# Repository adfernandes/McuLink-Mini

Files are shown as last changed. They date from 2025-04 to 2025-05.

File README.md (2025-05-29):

# MCU-Link with KiCAD
This repository hosts different versions of the original NXP MCU-Link CMSIS-DAP debug probe as open source KiCAD versions. Both as standalone probe or integrated into your design.

Many thanks to *Dario Scheuber* and his work to make this project possible!

## Background
This is the work of Dario Scheuber who created this debug probe as student at the Lucerne University of Applied Sciences and Arts at [IET](https://www.hslu.ch/en/lucerne-school-of-engineering-architecture/about-us/organization/institute/engineering-and-technology/elektrotechnik/). The project was done under the guidance of Prof. Erich Styger.

See blog article on https://mcuoneclipse.com/2024/02/06/versatile-oshw-mini-mcu-link-debug-probe-external-on-board-or-embedded/ for additional details.

## Features
This is an open hardware version of the NXP MCU-Link CMSIS-DAP debug probe, with following features and differences to the original MCU-Link:
- Open hardware design with KiCad
- Firmware compatibility with MCU-Link (LinkServer, CMSIS-DAP, ARM DAPLink)
- Dual-Layer design for lower costs
- USB-C connector instead of  Micro-USB
- USB-C connector usable to debug the LPC55S69
- 30% smaller than the original MCU-Link
- Firmware/boot push button instead of jumper
- Micro connector for UART connection instead of pin header
- Supports only 3.3V targets (no level shifters)
- Standalone version as external debug probe
- On-Board version: Solder external debug probe on your custom board (castellated pins)
- Embedded version: copy-paste into your custom board KiCad design
- BOM with assembly costs: ~$12/piece for 100 units

top PCB
bottom PCB

## Folders
- enclosure: 3D printed enclosure
- hardware: KiCad and hardware related files

## Links
- Article: https://mcuoneclipse.com/2024/02/06/versatile-oshw-mini-mcu-link-debug-probe-external-on-board-or-embedded/
- NXP MCU-Link: https://www.nxp.com/design/design-center/software/development-software/mcuxpresso-software-and-tools-/mcu-link-debug-probe:MCU-LINK
- KiCad: https://www.kicad.org/

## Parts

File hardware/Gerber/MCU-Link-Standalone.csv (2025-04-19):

ID | Label | Footprint | Number | Description, Value | Reference
1 | JP1 | SolderJumper-2_P1.3mm_Open_RoundedPad1.0x1.5mm | 1 | SWD disable
2 | C22,C15,C26 | C_0402_1005Metric | 3 | 22u
3 | C21,C24 | C_0402_1005Metric | 2 | 8p
4 | J2 | JST_BM03B-SRSS-TB_LF__SN_ | 1 | BM03B-SRSS-TB
5 | U2 | LQFP-64-1EP_10x10mm_P0.5mm_EP5x5mm | 1 | LPC55S69JBD64
6 | L5 | L_0603_1608Metric | 1 | 4u7
7 | C8,C7,C25,C9,C5,C2,C18,C4,C11,C17 | C_0402_1005Metric | 10 | 100n
8 | D5,D2 | SOT-666 | 2 | PESD5V0L5UV
9 | Q2,Q3,Q1 | SOT1216 | 3 | PMDXB290UNE
10 | C10,C1 | C_0402_1005Metric | 2 | 10u
11 | R12,R6,R8,R5,R7,R9 | R_0402_1005Metric | 6 | 100
12 | C23,C19,C20 | C_0402_1005Metric | 3 | 47p
13 | SW1 | SW_C_K_KMR2 | 1 | KMR221GLFS
14 | D1 | SOT143B | 1 | PRTR5V0U2X
15 | R1,R2 | R_0402_1005Metric | 2 | 5k1
16 | U1 | SOT-89-5 | 1 | XC6227C331PR-G
17 | D3 | LED_0402_1005Metric | 1 | LED_RED
18 | C13,C6,C14,C12,C16 | C_0402_1005Metric | 5 | 10n
19 | L3,L4,L2 | L_0603_1608Metric | 3 | MI0603J601R-10
20 | R13,R14 | R_0402_1005Metric | 2 | 100k
21 | R11,R15 | R_0402_1005Metric | 2 | 2k
22 | R4 | R_0402_1005Metric | 1 | 20k
23 | U3 | SOT95P280X145-5N | 1 | STMPS2141STR
24 | D4 | Nexperia_DSN0603-2_0.6x0.3mm_P0.4mm | 1 | PMEG3005AESFYL
25 | J1 | USB_C_Receptacle_GCT_USB4110-GF-A | 1 | USB4110-GF-A_REVB
26 | R10,R3 | R_0402_1005Metric | 2 | 10k
27 | Y1 | CX3225GA16000D0PTVCC | 1 | 16.000MHz
28 | C3 | C_0402_1005Metric | 1 | 4u7
29 | R16 | R_0402_1005Metric | 1 | 10
30 | J3 | SWD_Pin_Header_Straight_2x05_Pitch1.27mm_SMD | 1 | Conn_02x05_Odd_Even

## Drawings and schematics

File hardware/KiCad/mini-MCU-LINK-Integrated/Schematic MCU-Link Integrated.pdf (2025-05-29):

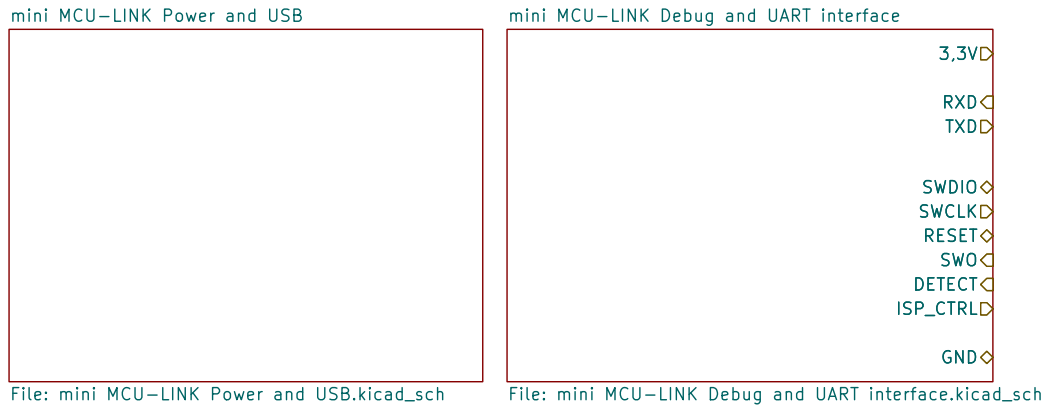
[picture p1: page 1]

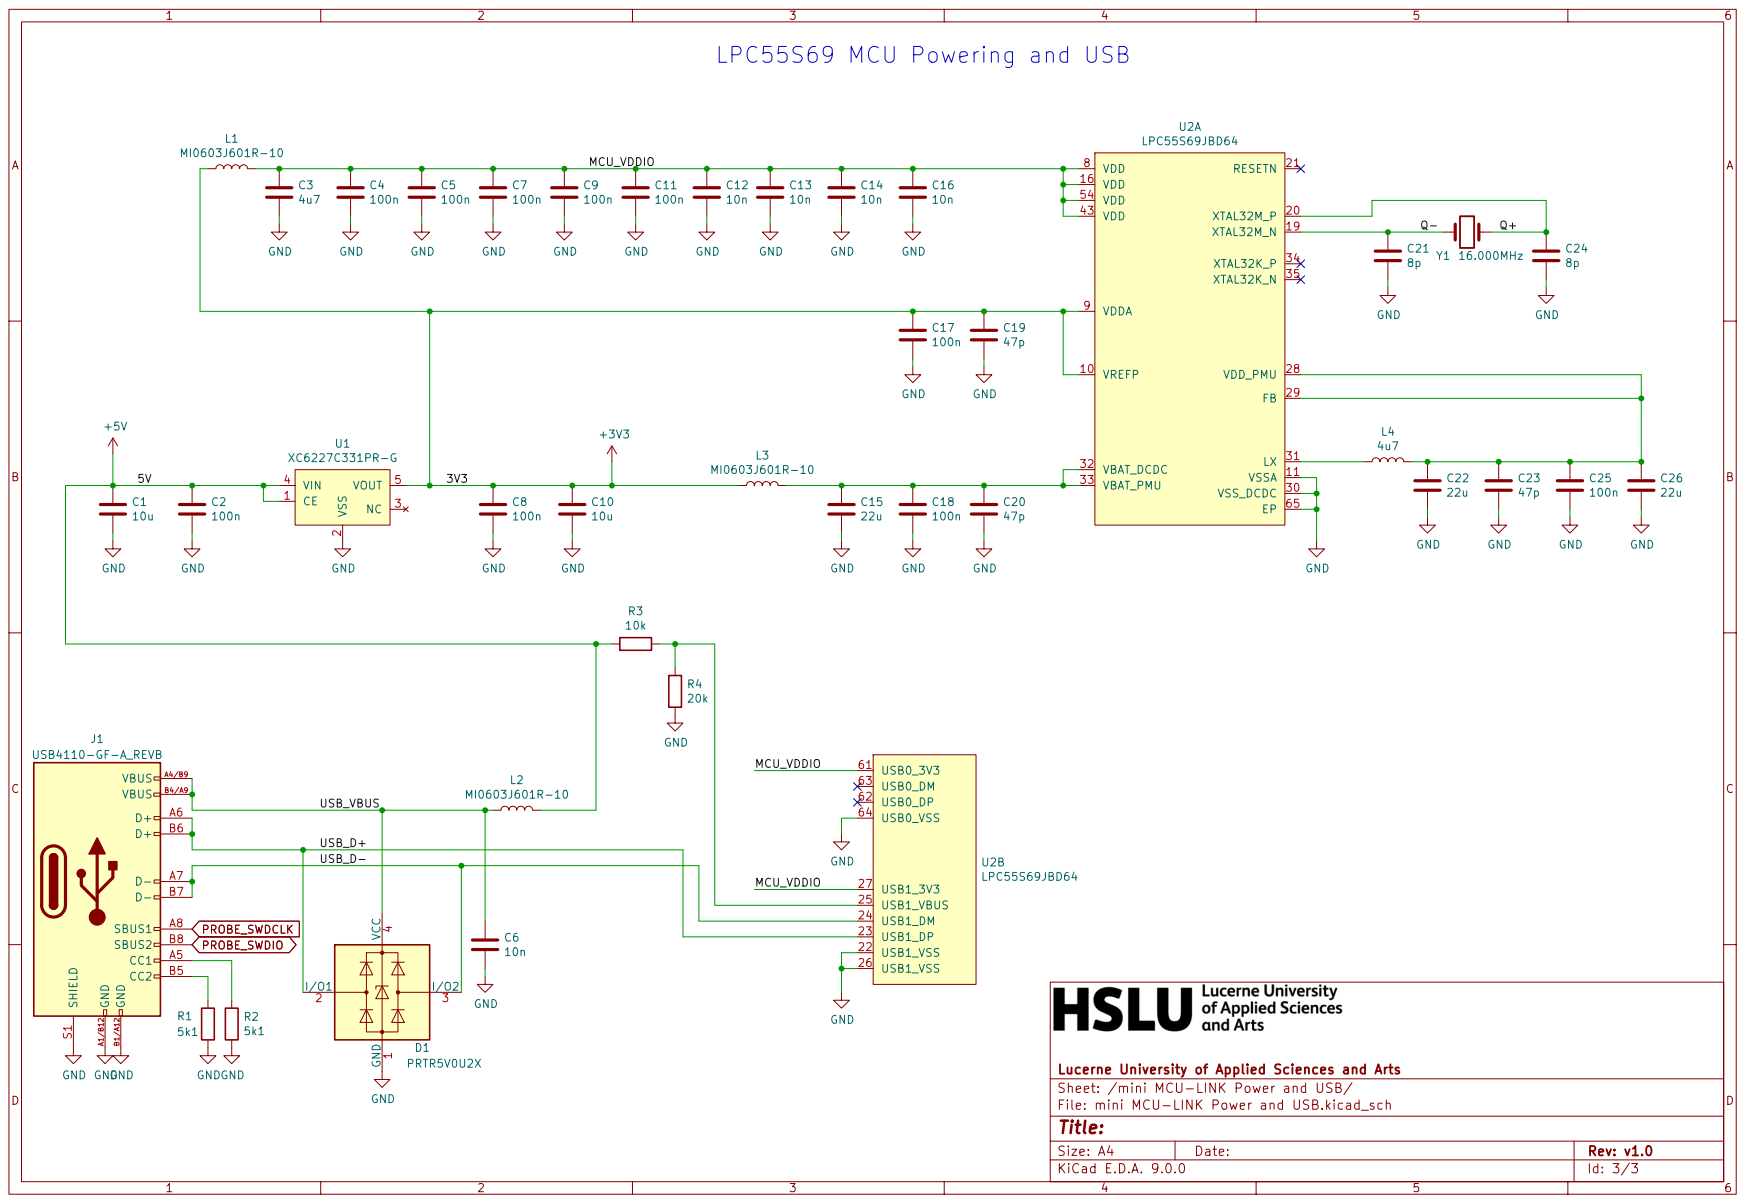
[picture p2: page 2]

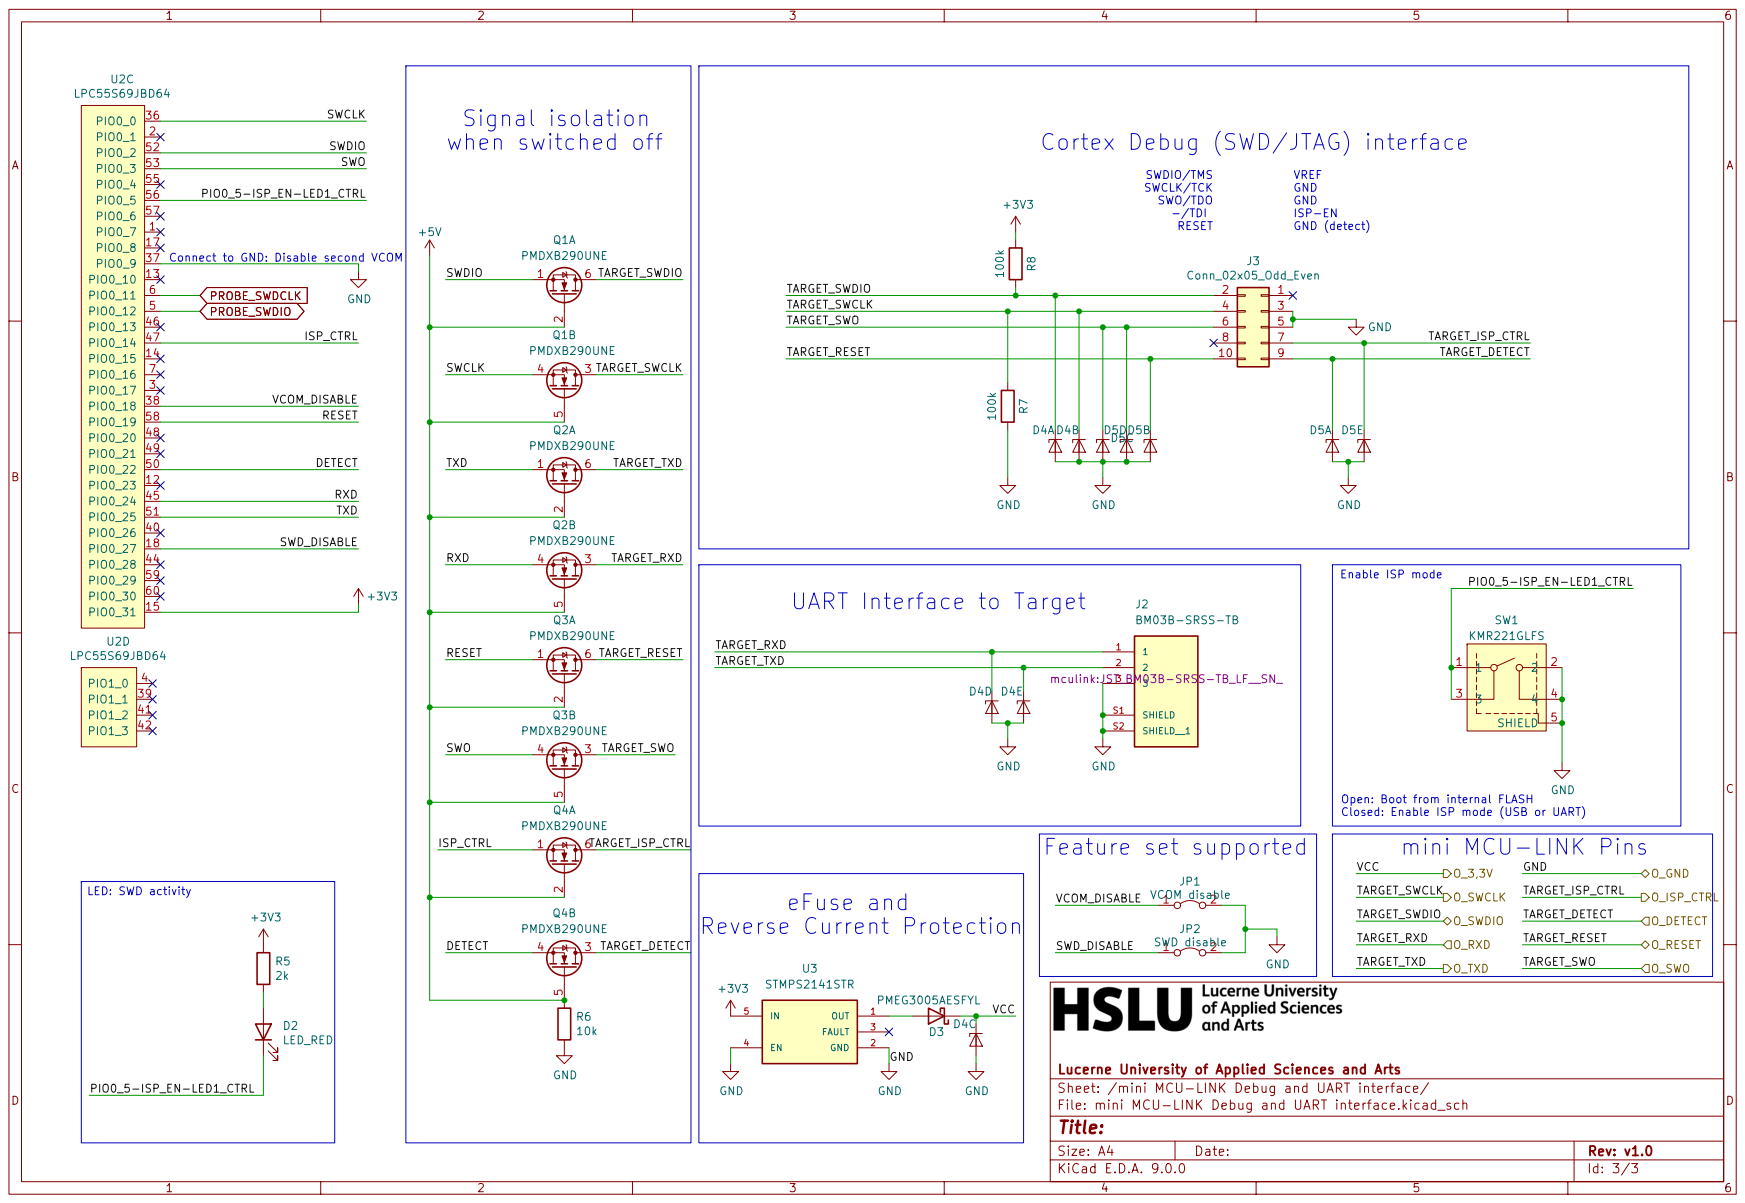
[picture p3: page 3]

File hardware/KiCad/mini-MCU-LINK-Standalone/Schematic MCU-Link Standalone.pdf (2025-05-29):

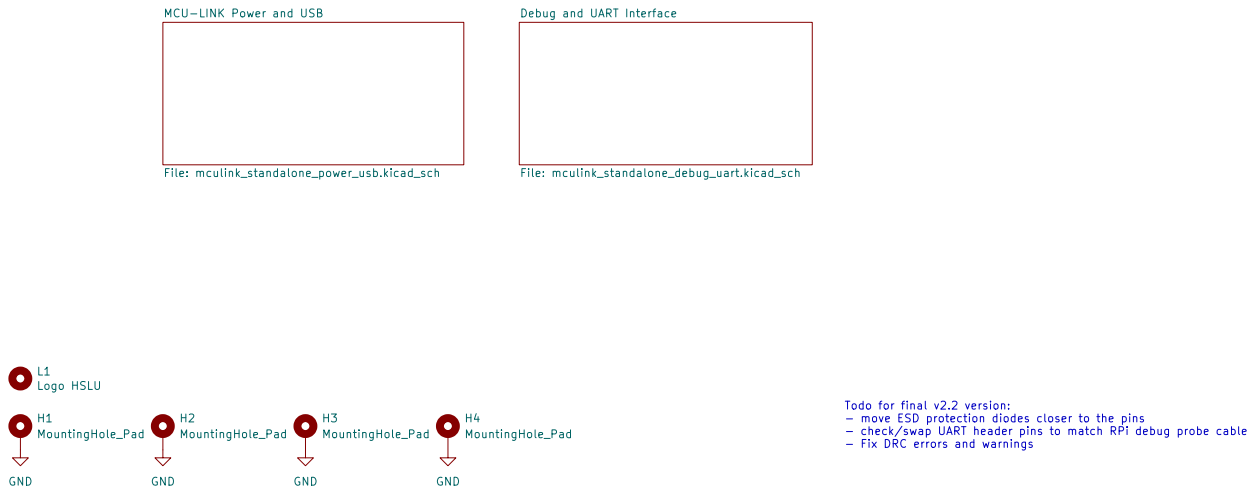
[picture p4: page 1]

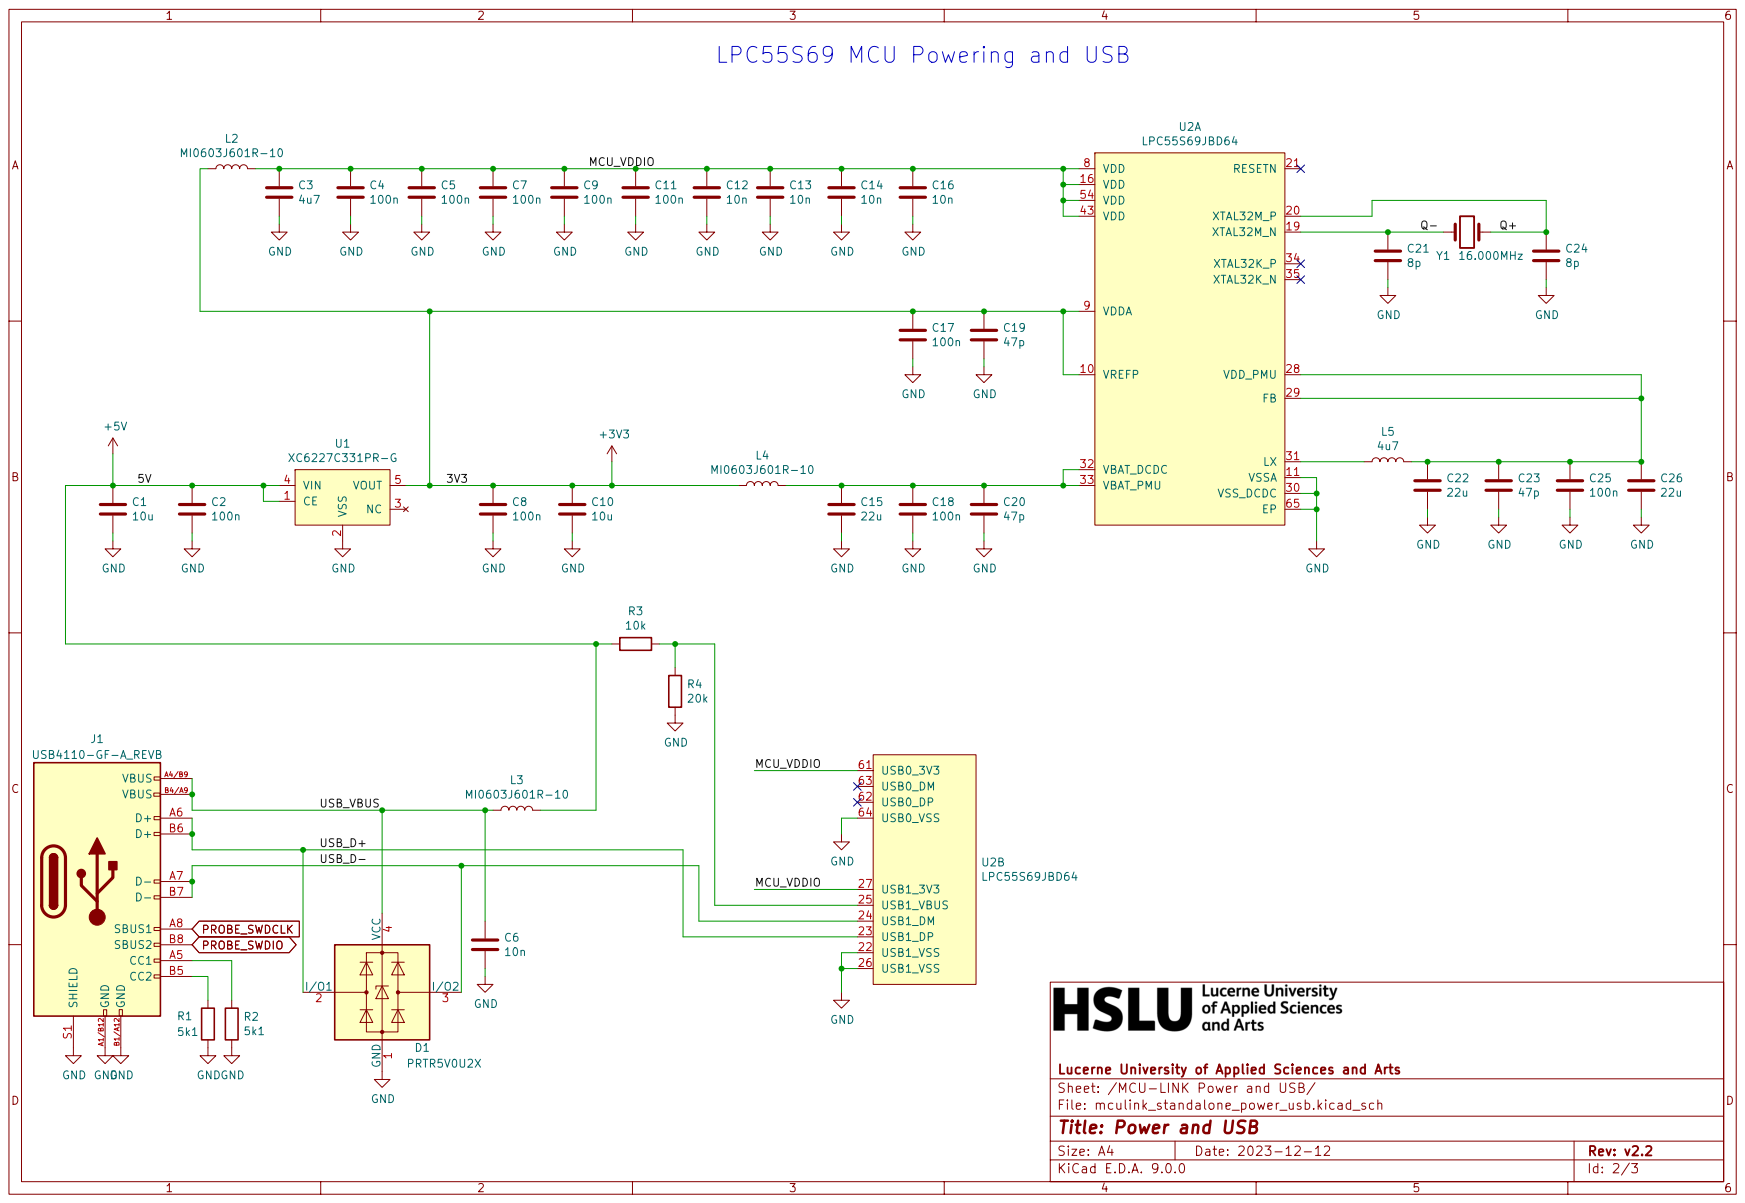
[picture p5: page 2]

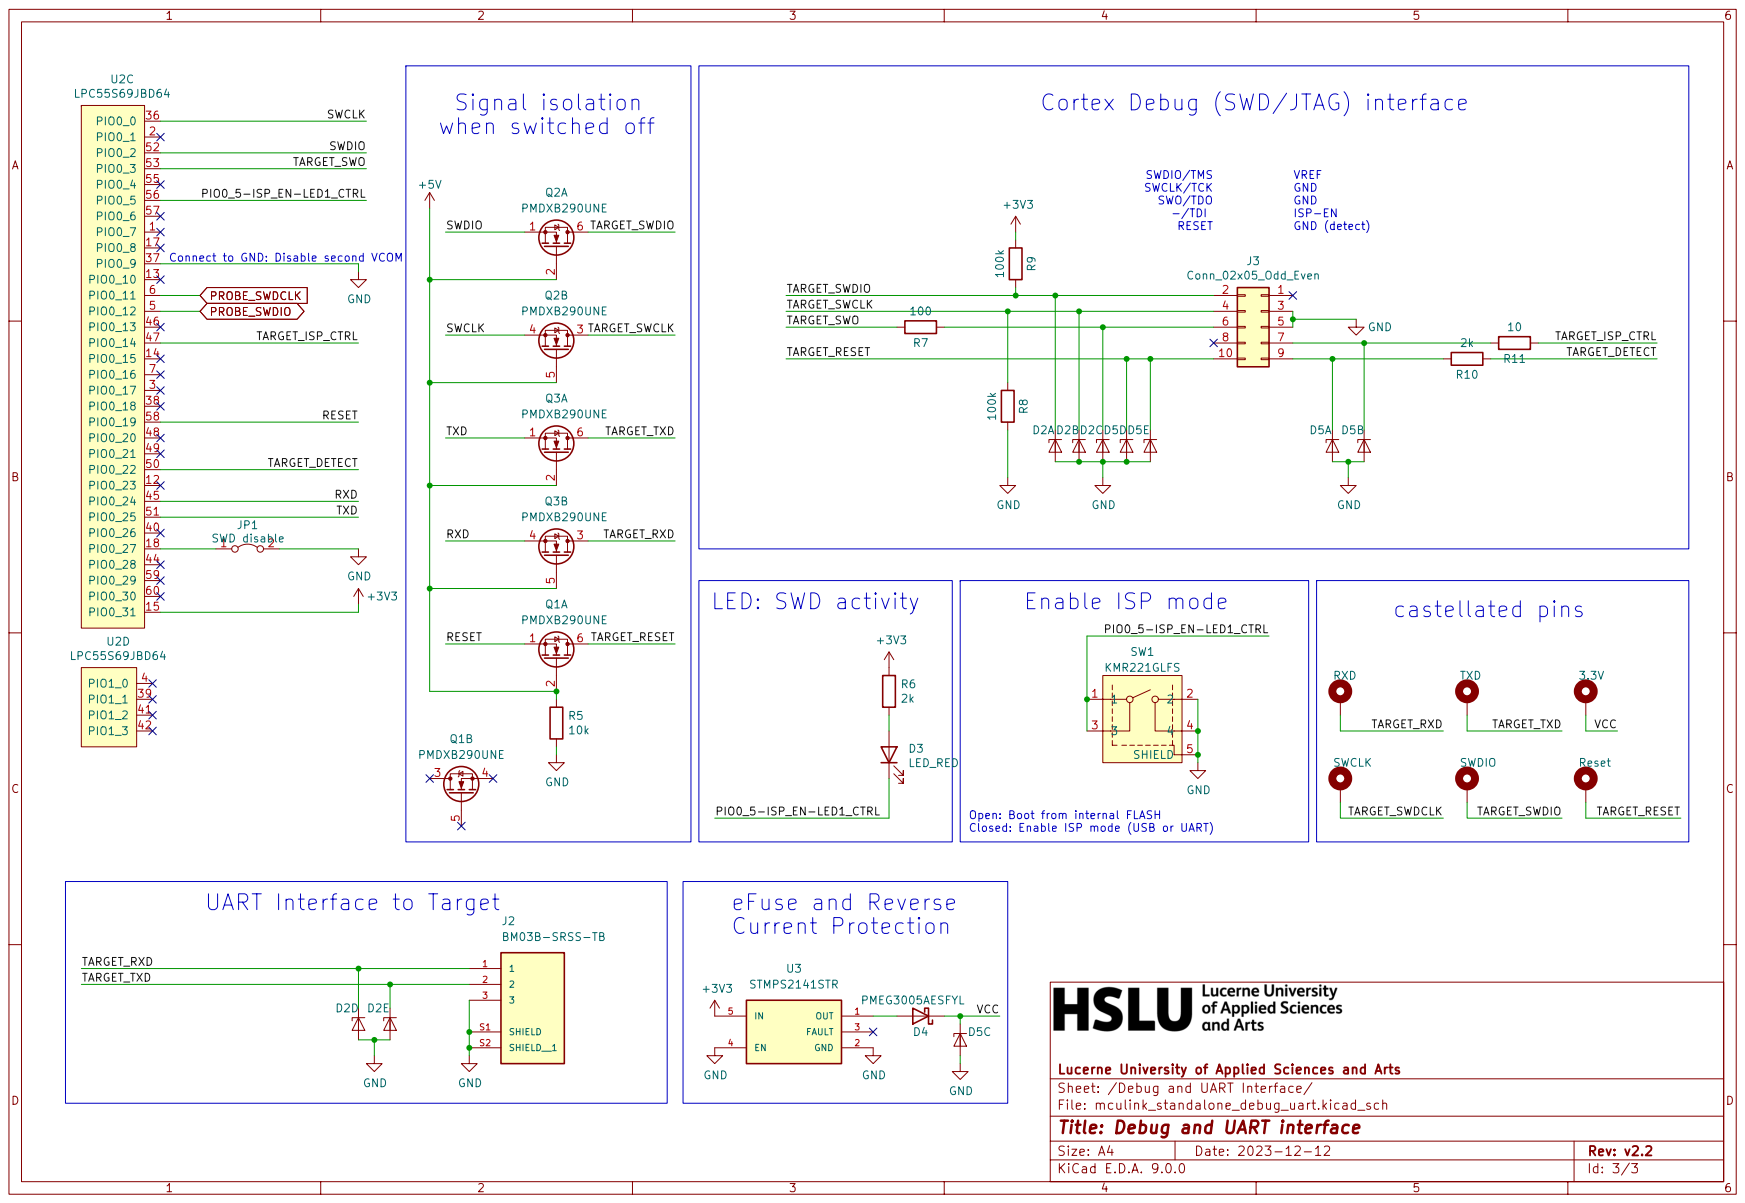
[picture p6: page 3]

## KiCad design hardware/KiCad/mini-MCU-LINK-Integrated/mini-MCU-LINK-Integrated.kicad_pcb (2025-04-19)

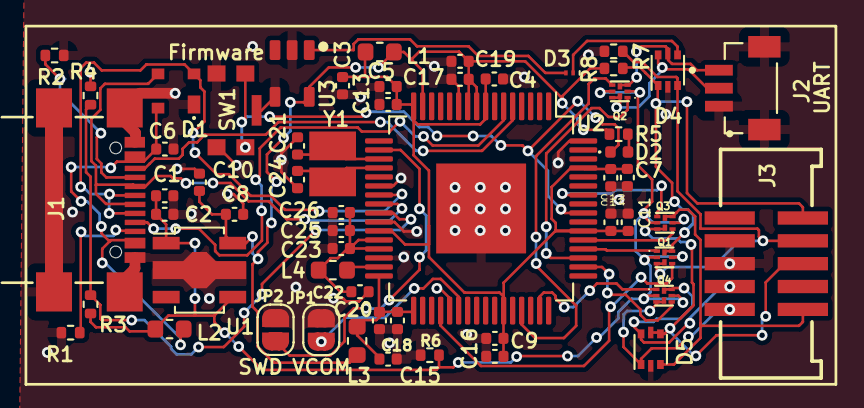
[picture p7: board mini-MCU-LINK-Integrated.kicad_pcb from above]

Board: 2 copper layers, 57 parts (0 on the bottom side), 39 nets.

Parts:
C1, C10: 10u; C_0402_1005Metric
C2, C4, C5, C7, C8, C9, C11, C17, C18, C25: 100n; C_0402_1005Metric
C3: 4u7; C_0402_1005Metric
C6, C12, C13, C14, C16: 10n; C_0402_1005Metric
C15, C22, C26: 22u; C_0402_1005Metric
C19, C20, C23: 47p; C_0402_1005Metric
C21, C24: 8p; C_0402_1005Metric
D1: PRTR5V0U2X; SOT143B
D2: LED_RED; LED_0402_1005Metric
D3: PMEG3005AESFYL; Nexperia_DSN0603-2_0.6x0.3mm_P0.4mm
D4, D5: PESD5V0L5UV; SOT-666
J1: USB4110-GF-A_REVB; USB_C_Receptacle_GCT_USB4110-GF-A
J2: BM03B-SRSS-TB; JST_BM03B-SRSS-TB_LF__SN_
J3: Conn_02x05_Odd_Even; SWD_Pin_Header_Straight_2x05_Pitch1.27mm_SMD
JP1: VCOM disable; SolderJumper-2_P1.3mm_Open_RoundedPad1.0x1.5mm
JP2: SWD disable; SolderJumper-2_P1.3mm_Open_RoundedPad1.0x1.5mm
L1, L2, L3: MI0603J601R-10; L_0603_1608Metric
L4: 4u7; L_0603_1608Metric
Q1, Q2, Q3, Q4: PMDXB290UNE; SOT1216
R1, R2: 5k1; R_0402_1005Metric
R3, R6: 10k; R_0402_1005Metric
R4: 20k; R_0402_1005Metric
R5: 2k; R_0402_1005Metric
R7, R8: 100k; R_0402_1005Metric
SW1: KMR221GLFS; SW_C_K_KMR2
U1: XC6227C331PR-G; SOT-89-5
U2: LPC55S69JBD64; LQFP-64-1EP_10x10mm_P0.5mm_EP5x5mm
U3: STMPS2141STR; SOT95P280X145-5N
Y1: 16.000MHz; CX3225GA16000D0PTVCC

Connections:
+3V3: C8.1, C10.1, C17.1, C19.1, L1.1, L3.1, R5.1, R8.1, U1.5 (VOUT), U2.9 (VDDA), U2.10 (VREFP), U2.15 (PIO0_31), U3.5 (IN)
+5V: C1.1, C2.1, L2.2, Q1.2 (G), Q1.5 (G), Q2.2 (G), Q2.5 (G), Q3.2 (G), Q3.5 (G), Q4.2 (G), Q4.5 (G), R3.2, R6.1, U1.1 (CE), U1.4 (VIN)
/mini MCU-LINK Debug and UART interface/DETECT: Q4.4 (S), U2.50 (PIO0_22)
/mini MCU-LINK Debug and UART interface/ISP_CTRL: Q4.1 (S), U2.47 (PIO0_14)
/mini MCU-LINK Debug and UART interface/PIO0_5-ISP_EN-LED1_CTRL: D2.1 (K), SW1.1, SW1.3, U2.56 (PIO0_5)
/mini MCU-LINK Debug and UART interface/RESET: Q3.1 (S), U2.58 (PIO0_19)
/mini MCU-LINK Debug and UART interface/RXD: Q2.4 (S), U2.45 (PIO0_24)
/mini MCU-LINK Debug and UART interface/SWCLK: Q1.4 (S), U2.36 (PIO0_0)
/mini MCU-LINK Debug and UART interface/SWDIO: Q1.1 (S), U2.52 (PIO0_2)
/mini MCU-LINK Debug and UART interface/SWD_DISABLE: JP2.1 (A), U2.18 (PIO0_27)
/mini MCU-LINK Debug and UART interface/SWO: Q3.4 (S), U2.53 (PIO0_3)
/mini MCU-LINK Debug and UART interface/TARGET_DETECT: D5.1 (K1), J3.9, Q4.3 (D)
/mini MCU-LINK Debug and UART interface/TARGET_ISP_CTRL: D5.6 (K5), J3.7, Q4.6 (D)
/mini MCU-LINK Debug and UART interface/TARGET_RESET: D5.3 (K2), J3.10, Q3.6 (D)
/mini MCU-LINK Debug and UART interface/TARGET_RXD: D4.5 (K4), J2.1, Q2.3 (D)
/mini MCU-LINK Debug and UART interface/TARGET_SWCLK: D4.3 (K2), J3.4, Q1.3 (D), R7.1
/mini MCU-LINK Debug and UART interface/TARGET_SWDIO: D4.1 (K1), J3.2, Q1.6 (D), R8.2
/mini MCU-LINK Debug and UART interface/TARGET_SWO: D5.4 (K3), D5.5 (K4), J3.6, Q3.3 (D)
/mini MCU-LINK Debug and UART interface/TARGET_TXD: D4.6 (K5), J2.2, Q2.6 (D)
/mini MCU-LINK Debug and UART interface/TXD: Q2.1 (S), U2.51 (PIO0_25)
/mini MCU-LINK Debug and UART interface/VCC: D3.1 (K), D4.4 (K3)
/mini MCU-LINK Debug and UART interface/VCOM_DISABLE: JP1.1 (A), U2.38 (PIO0_18)
/mini MCU-LINK Power and USB/MCU_VDDIO: C3.1, C4.1, C5.1, C7.1, C9.1, C11.1, C12.1, C13.1, C14.1, C16.1, L1.2, U2.8 (VDD), U2.16 (VDD), U2.27 (USB1_3V3), U2.43 (VDD), U2.54 (VDD), U2.61 (USB0_3V3)
/mini MCU-LINK Power and USB/Q+: C24.1, U2.20 (XTAL32M_P), Y1.2
/mini MCU-LINK Power and USB/Q-: C21.1, U2.19 (XTAL32M_N), Y1.1
/mini MCU-LINK Power and USB/USB_D+: D1.2 (I/O1), J1.A6 (D+), J1.B6 (D+), U2.23 (USB1_DP)
/mini MCU-LINK Power and USB/USB_D-: D1.3 (I/O2), J1.A7 (D-), J1.B7 (D-), U2.24 (USB1_DM)
/mini MCU-LINK Power and USB/USB_VBUS: C6.1, D1.4 (VCC), J1.A4/B9 (VBUS), J1.B4/A9 (VBUS), L2.1
GND: C1.2, C2.2, C3.2, C4.2, C5.2, C6.2, C7.2, C8.2, C9.2, C10.2, C11.2, C12.2, C13.2, C14.2, C15.2, C16.2, C17.2, C18.2, C19.2, C20.2, C21.2, C22.2, C23.2, C24.2, C25.2, C26.2, D1.1 (GND), D4.2 (A), D5.2 (A), J1.A1/B12 (GND), J1.B1/A12 (GND), J1.S1 (SHIELD), J2.3, J2.S1 (SHIELD), J2.S2 (SHIELD__1), J3.3, J3.5, JP1.2 (B), JP2.2 (B), R1.1, R2.1, R4.1, R6.2, R7.2, SW1.2, SW1.4, SW1.5 (SHIELD), U1.2 (VSS), U2.11 (VSSA), U2.22 (USB1_VSS), U2.26 (USB1_VSS), U2.30 (VSS_DCDC), U2.37 (PIO0_9), U2.64 (USB0_VSS), U2.65 (EP), U3.2 (GND), U3.4 (EN)
unnamed: D2.2 (A), R5.2
unnamed: D3.2 (A), U3.1 (OUT)
unnamed: J1.A5 (CC1), R2.2
unnamed: J1.B5 (CC2), R1.2
unnamed: C22.1, C23.1, C25.1, C26.1, L4.2, U2.28 (VDD_PMU), U2.29 (FB)
unnamed: L4.1, U2.31 (LX)
unnamed: C15.1, C18.1, C20.1, L3.2, U2.32 (VBAT_DCDC), U2.33 (VBAT_PMU)
unnamed: R3.1, R4.2, U2.25 (USB1_VBUS)
PROBE_SWDCLK: J1.A8 (SBUS1), U2.6 (PIO0_11)
PROBE_SWDIO: J1.B8 (SBUS2), U2.5 (PIO0_12)

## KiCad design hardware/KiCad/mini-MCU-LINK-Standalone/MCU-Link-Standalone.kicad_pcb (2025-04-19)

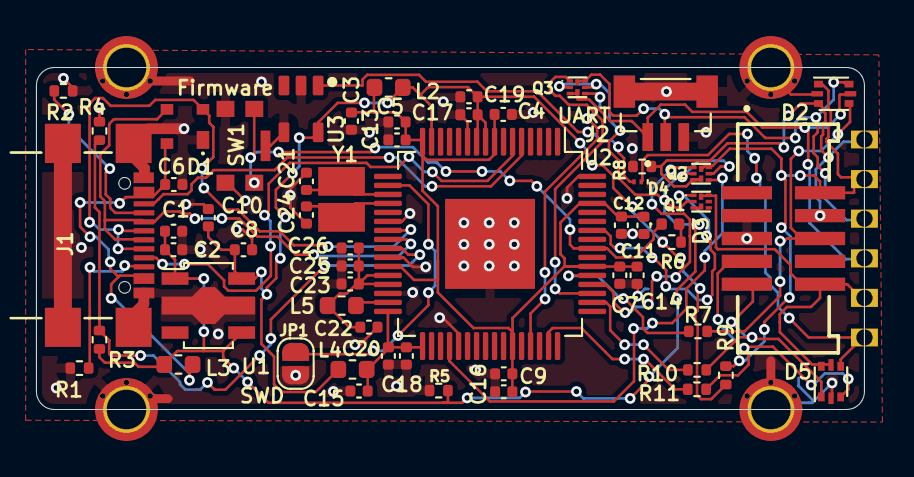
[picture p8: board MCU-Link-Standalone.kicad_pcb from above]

Board: 2 copper layers, 46.0 x 19.0 mm, 69 parts (1 on the bottom side), 38 nets.

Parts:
C1, C10: 10u; C_0402_1005Metric
C2, C4, C5, C7, C8, C9, C11, C17, C18, C25: 100n; C_0402_1005Metric
C3: 4u7; C_0402_1005Metric
C6, C12, C13, C14, C16: 10n; C_0402_1005Metric
C15, C22, C26: 22u; C_0402_1005Metric
C19, C20, C23: 47p; C_0402_1005Metric
C21, C24: 8p; C_0402_1005Metric
D1: PRTR5V0U2X; SOT143B
D2, D5: PESD5V0L5UV; SOT-666
D3: LED_RED; LED_0402_1005Metric
D4: PMEG3005AESFYL; Nexperia_DSN0603-2_0.6x0.3mm_P0.4mm
H1, H2, H3, H4: MountingHole_Pad; MountingHole_2.2mm_M2_ISO7380_Pad_TopBottom_with_holes
H5: RXD; castellated pin
H6: SWCLK; castellated pin
H7: TXD; castellated pin
H8: SWDIO; castellated pin
H9: 3.3V; castellated pin
H10: Reset; castellated pin
J1: USB4110-GF-A_REVB; USB_C_Receptacle_GCT_USB4110-GF-A
J2: BM03B-SRSS-TB; JST_BM03B-SRSS-TB_LF__SN_
J3: Conn_02x05_Odd_Even; SWD_Pin_Header_Straight_2x05_Pitch1.27mm_SMD
JP1: SWD disable; SolderJumper-2_P1.3mm_Open_RoundedPad1.0x1.5mm
L1: Logo HSLU; Hochschule_Luzern_New
L2, L3, L4: MI0603J601R-10; L_0603_1608Metric
L5: 4u7; L_0603_1608Metric
Q1, Q2, Q3: PMDXB290UNE; SOT1216
R1, R2: 5k1; R_0402_1005Metric
R3, R5: 10k; R_0402_1005Metric
R4: 20k; R_0402_1005Metric
R6, R10: 2k; R_0402_1005Metric
R7: 100; R_0402_1005Metric
R8, R9: 100k; R_0402_1005Metric
R11: 10; R_0402_1005Metric
SW1: KMR221GLFS; SW_C_K_KMR2
U1: XC6227C331PR-G; SOT-89-5
U2: LPC55S69JBD64; LQFP-64-1EP_10x10mm_P0.5mm_EP5x5mm
U3: STMPS2141STR; SOT95P280X145-5N
Y1: 16.000MHz; CX3225GA16000D0PTVCC

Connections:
+3V3: C8.1, C10.1, C17.1, C19.1, L2.1, L4.1, R6.1, R9.1, U1.5 (VOUT), U2.9 (VDDA), U2.10 (VREFP), U2.15 (PIO0_31), U3.5 (IN)
+5V: C1.1, C2.1, L3.2, Q1.2 (G), Q2.2 (G), Q2.5 (G), Q3.2 (G), Q3.5 (G), R3.2, R5.1, U1.1 (CE), U1.4 (VIN)
/Debug and UART Interface/PIO0_5-ISP_EN-LED1_CTRL: D3.1 (K), SW1.1, SW1.3, U2.56 (PIO0_5)
/Debug and UART Interface/RESET: Q1.1 (S), U2.58 (PIO0_19)
/Debug and UART Interface/RXD: Q3.4 (S), U2.45 (PIO0_24)
/Debug and UART Interface/SWCLK: Q2.4 (S), U2.36 (PIO0_0)
/Debug and UART Interface/SWDIO: Q2.1 (S), U2.52 (PIO0_2)
/Debug and UART Interface/TARGET_DETECT: R10.1, U2.50 (PIO0_22)
/Debug and UART Interface/TARGET_ISP_CTRL: R11.1, U2.47 (PIO0_14)
/Debug and UART Interface/TARGET_RESET: D5.5 (K4), D5.6 (K5), H10.1, J3.10, Q1.6 (D)
/Debug and UART Interface/TARGET_RXD: D2.5 (K4), H5.1, J2.1, Q3.3 (D)
/Debug and UART Interface/TARGET_SWCLK: D2.3 (K2), J3.4, Q2.3 (D), R8.1
/Debug and UART Interface/TARGET_SWDIO: D2.1 (K1), H8.1, J3.2, Q2.6 (D), R9.2
/Debug and UART Interface/TARGET_SWO: R7.2, U2.53 (PIO0_3)
/Debug and UART Interface/TARGET_TXD: D2.6 (K5), H7.1, J2.2, Q3.6 (D)
/Debug and UART Interface/TXD: Q3.1 (S), U2.51 (PIO0_25)
/Debug and UART Interface/VCC: D4.1 (K), D5.4 (K3), H9.1
/MCU-LINK Power and USB/MCU_VDDIO: C3.1, C4.1, C5.1, C7.1, C9.1, C11.1, C12.1, C13.1, C14.1, C16.1, L2.2, U2.8 (VDD), U2.16 (VDD), U2.27 (USB1_3V3), U2.43 (VDD), U2.54 (VDD), U2.61 (USB0_3V3)
/MCU-LINK Power and USB/Q+: C24.1, U2.20 (XTAL32M_P), Y1.2
/MCU-LINK Power and USB/Q-: C21.1, U2.19 (XTAL32M_N), Y1.1
/MCU-LINK Power and USB/USB_D+: D1.2 (I/O1), J1.A6 (D+), J1.B6 (D+), U2.23 (USB1_DP)
/MCU-LINK Power and USB/USB_D-: D1.3 (I/O2), J1.A7 (D-), J1.B7 (D-), U2.24 (USB1_DM)
/MCU-LINK Power and USB/USB_VBUS: C6.1, D1.4 (VCC), J1.A4/B9 (VBUS), J1.B4/A9 (VBUS), L3.1
GND: C1.2, C2.2, C3.2, C4.2, C5.2, C6.2, C7.2, C8.2, C9.2, C10.2, C11.2, C12.2, C13.2, C14.2, C15.2, C16.2, C17.2, C18.2, C19.2, C20.2, C21.2, C22.2, C23.2, C24.2, C25.2, C26.2, D1.1 (GND), D2.2 (A), D5.2 (A), H1.1, H2.1, H3.1, H4.1, J1.A1/B12 (GND), J1.B1/A12 (GND), J1.S1 (SHIELD), J2.3, J2.S1 (SHIELD), J2.S2 (SHIELD__1), J3.3, J3.5, JP1.2 (B), R1.1, R2.1, R4.1, R5.2, R8.2, SW1.2, SW1.4, SW1.5 (SHIELD), U1.2 (VSS), U2.11 (VSSA), U2.22 (USB1_VSS), U2.26 (USB1_VSS), U2.30 (VSS_DCDC), U2.37 (PIO0_9), U2.64 (USB0_VSS), U2.65 (EP), U3.2 (GND), U3.4 (EN)
unnamed: D2.4 (K3), J3.6, R7.1
unnamed: D3.2 (A), R6.2
unnamed: D4.2 (A), U3.1 (OUT)
unnamed: D5.1 (K1), J3.9, R10.2
unnamed: D5.3 (K2), J3.7, R11.2
unnamed: J1.A5 (CC1), R2.2
unnamed: J1.B5 (CC2), R1.2
unnamed: JP1.1 (A), U2.18 (PIO0_27)
unnamed: C22.1, C23.1, C25.1, C26.1, L5.2, U2.28 (VDD_PMU), U2.29 (FB)
unnamed: L5.1, U2.31 (LX)
unnamed: C15.1, C18.1, C20.1, L4.2, U2.32 (VBAT_DCDC), U2.33 (VBAT_PMU)
unnamed: R3.1, R4.2, U2.25 (USB1_VBUS)
PROBE_SWDCLK: J1.A8 (SBUS1), U2.6 (PIO0_11)
PROBE_SWDIO: J1.B8 (SBUS2), U2.5 (PIO0_12)

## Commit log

2025-04-19 Remove extraneous PMEG3005AESFYL whitespace/newline
    [MCU-Link-Standalone.csv, MCU-Link-Standalone.kicad_pcb, mculink_standalone_debug_uart.kicad_sch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]
2025-05-29 added schematic files
2025-10-29 Cleanup, MR version is hosted in different repository here: https://github.com/ErichStyger/MCU-Link-MR
    [1077192-MCU-Link-revPA6_pcb.brd, BOM.xlsx, MCU-Link_MR.kicad_pcb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]
